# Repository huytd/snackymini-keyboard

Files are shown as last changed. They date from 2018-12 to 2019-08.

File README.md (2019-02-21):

# Snackymini Keyboard

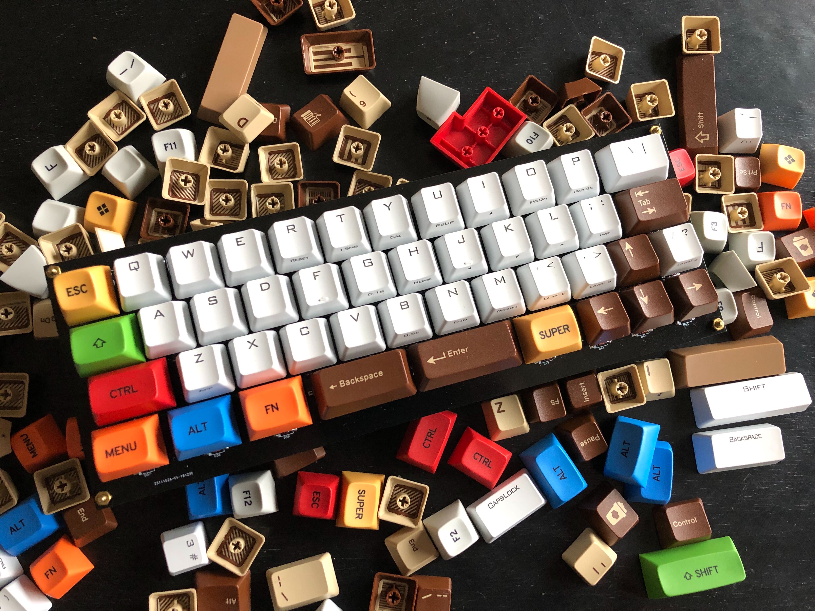
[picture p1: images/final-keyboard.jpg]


<details>
<summary>See more about design and PCB layout</summary>

**QWERTY Layout:**

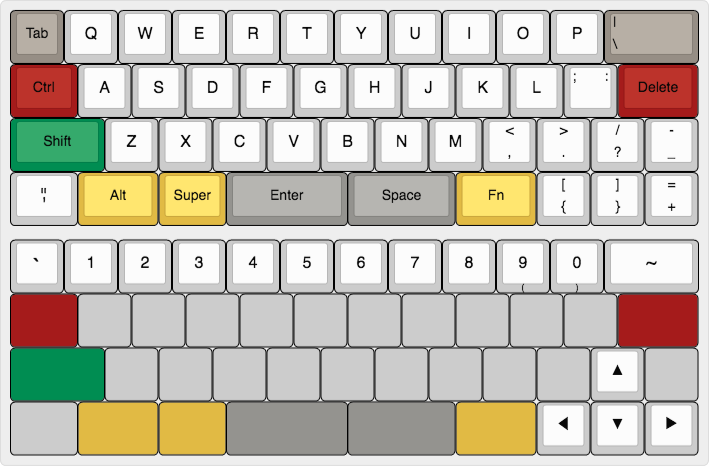
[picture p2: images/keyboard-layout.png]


**Dvorak Layout:**

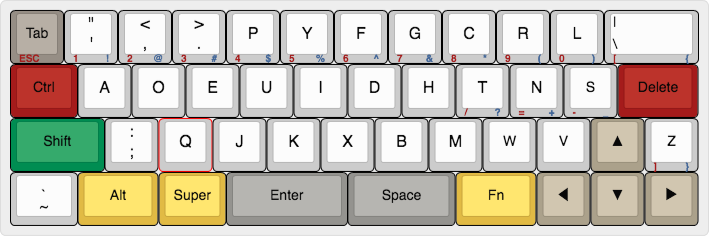
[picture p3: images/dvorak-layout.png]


Inspired by MiniVan Arrow Layout http://www.keyboard-layout-editor.com/#/gists/174470794149140f43dd6c9b544c168c

**Schema:**

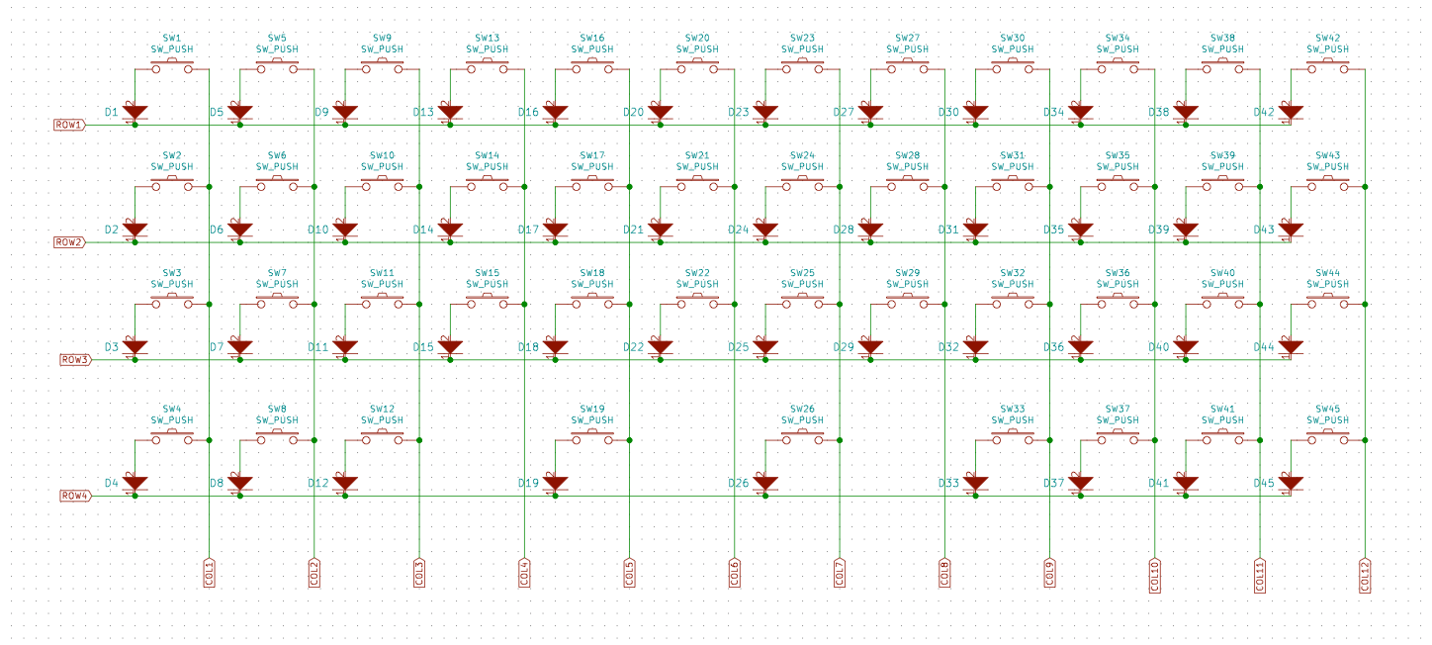
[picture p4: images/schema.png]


**PCB:**

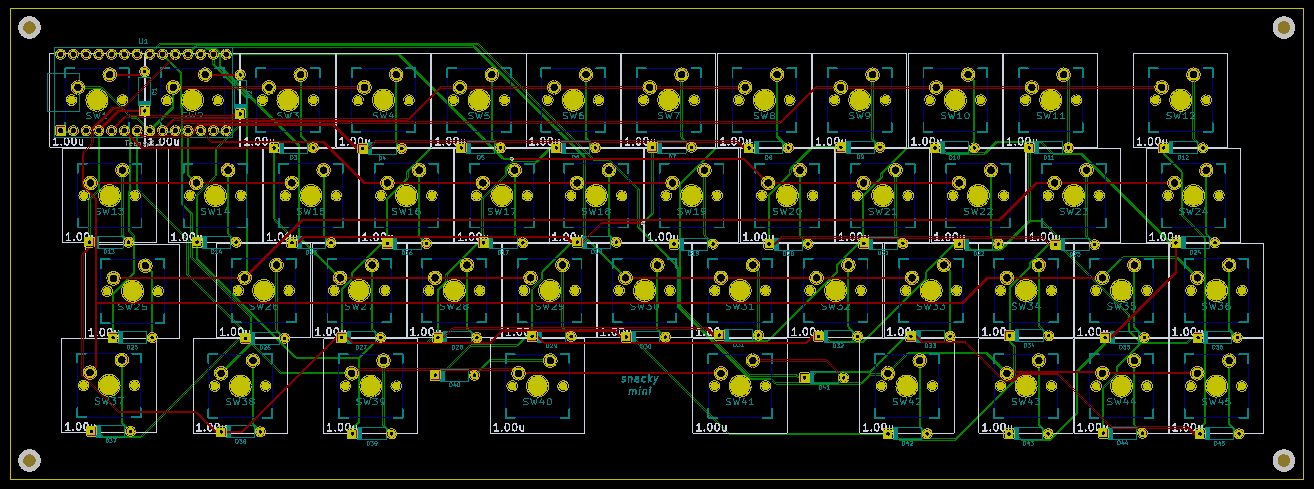
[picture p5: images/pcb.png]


**PCB render:**

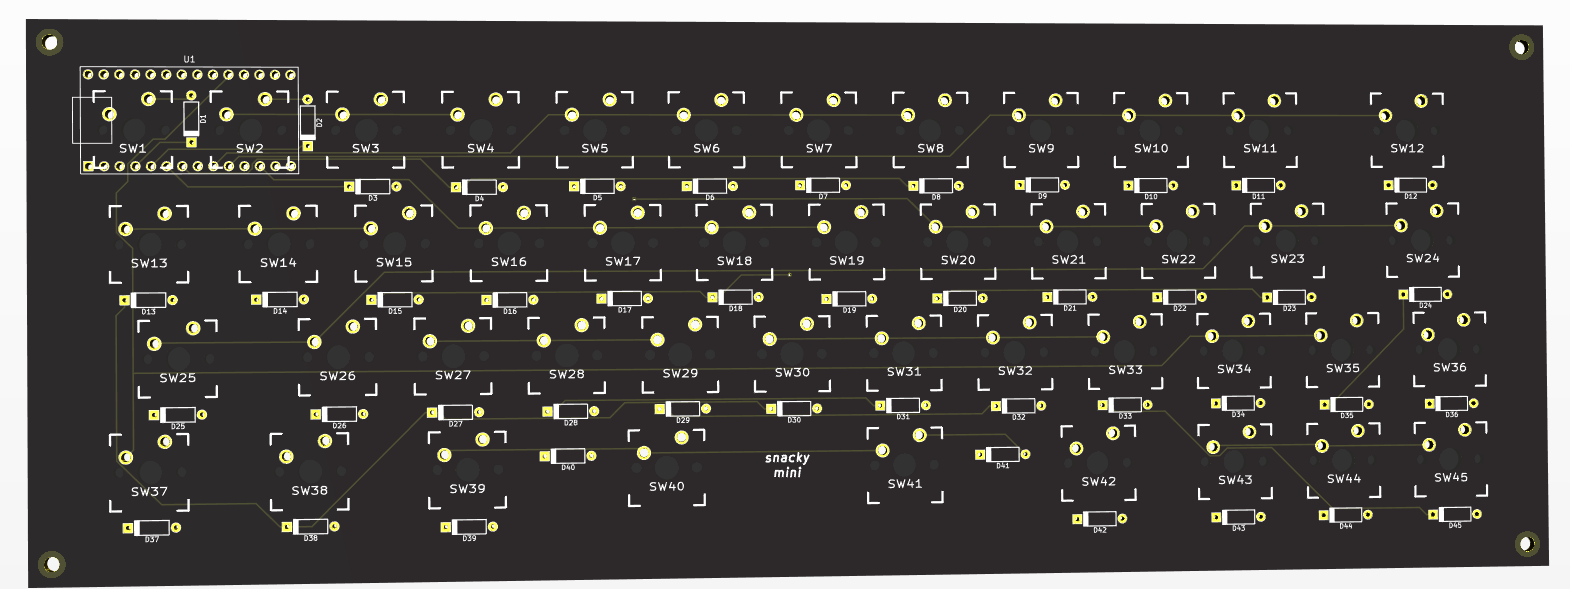
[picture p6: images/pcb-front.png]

</details>

## Parts
- 1x Teensy 3.2 with header pins
- 47x Cherry MX Switches (choose your color)
- 47x Key caps in various size
- 47x 1N4148 diodes

## How to use this repository?
First, you'll need to install [KiCad](http://kicad-pcb.org/), then you can open the PCB project in `hardware` folder to edit the PCB/Layout as you wish.

I have included the `snackymini-manufacturing-submission.zip` file containing all of the gerber files needed so you can send it to the manufacturer directly.

Ater having the PCB printed, you can use Arduino IDE (with Teensyduino installed) to compile the code in `firmware` folder, then upload it to your Teensy.

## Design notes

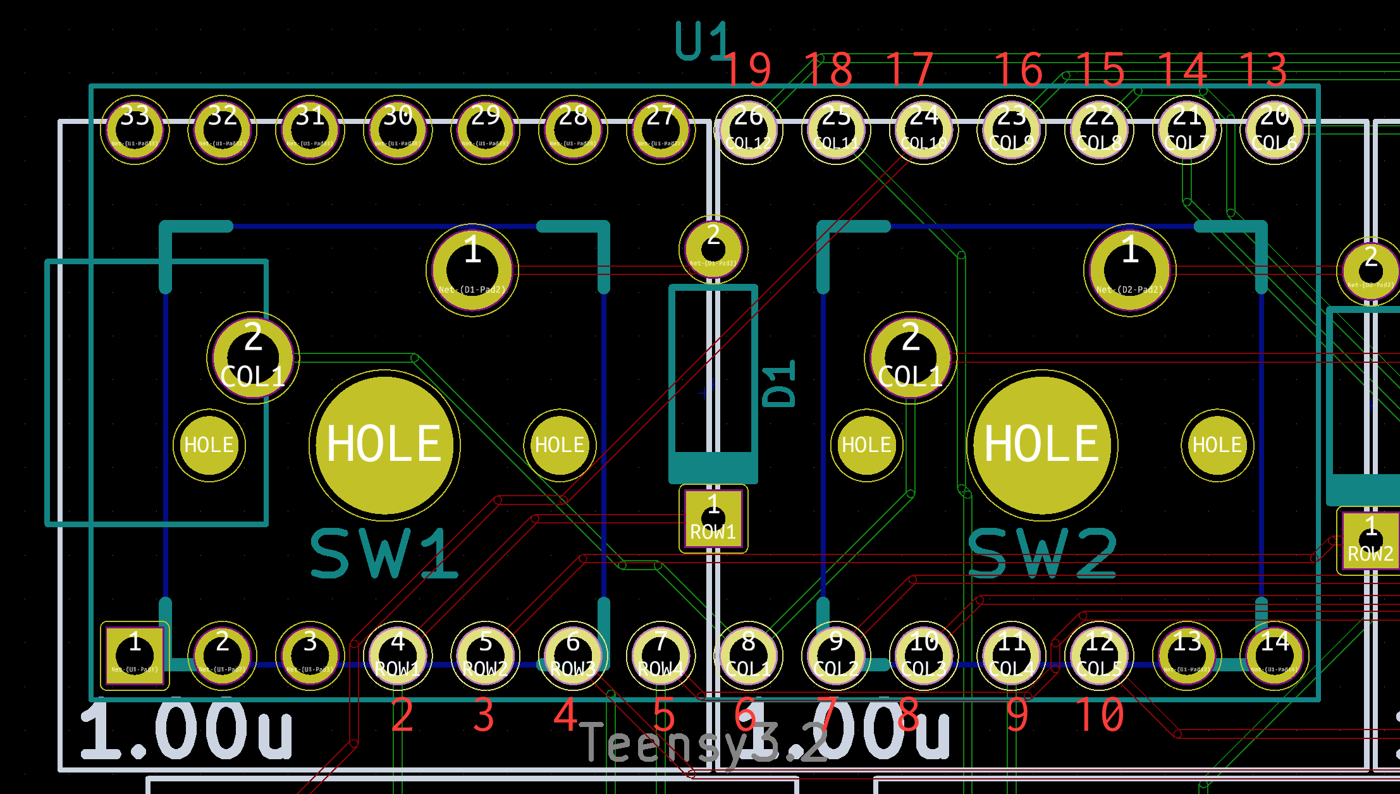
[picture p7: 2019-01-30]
images/pcb-pintout.png

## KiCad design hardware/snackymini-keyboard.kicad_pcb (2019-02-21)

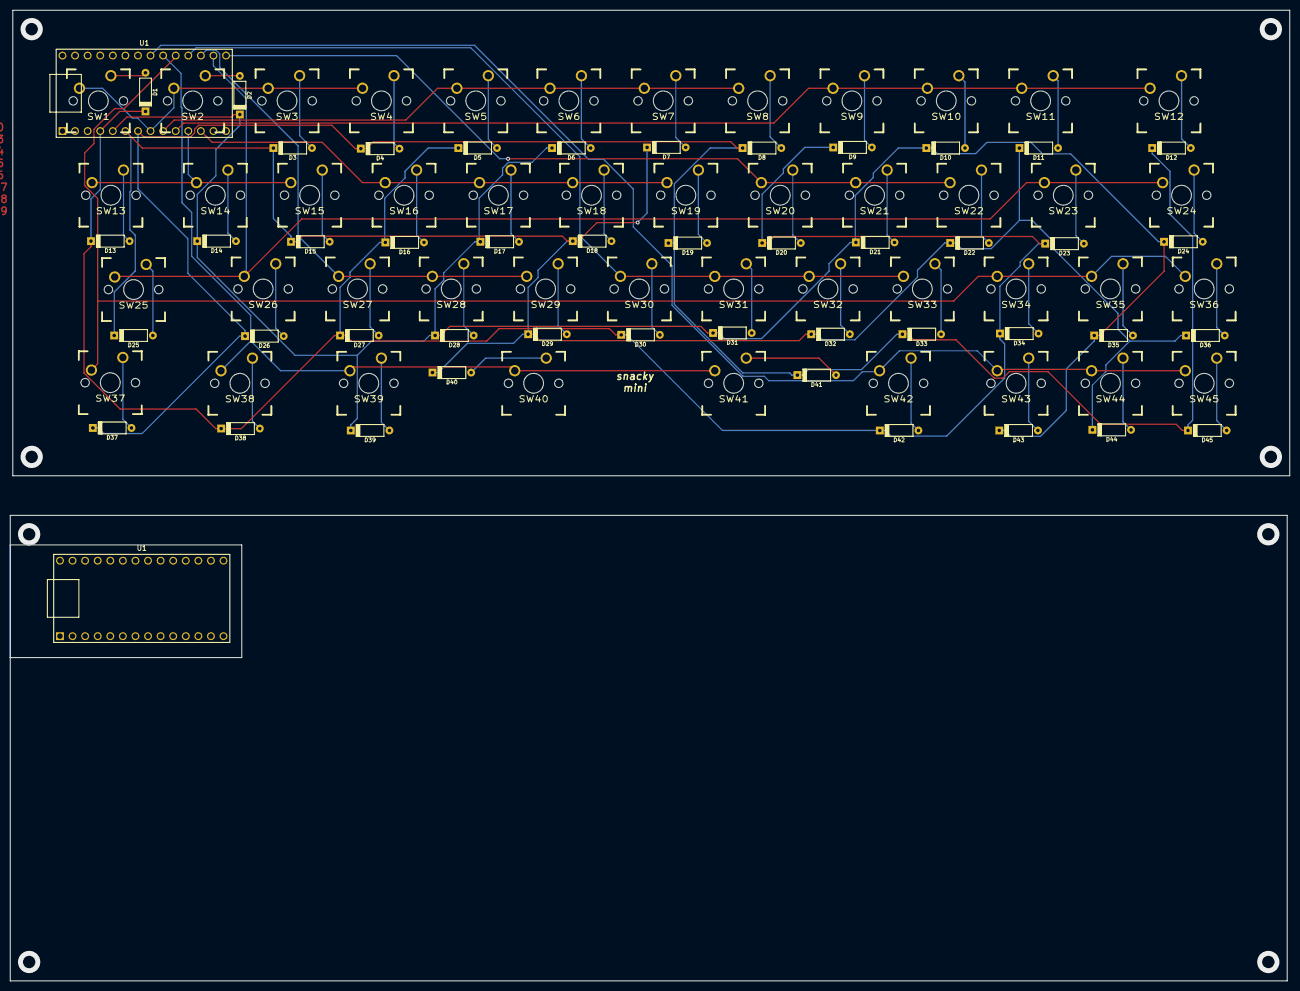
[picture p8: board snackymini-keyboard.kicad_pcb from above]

Board: 2 copper layers, 257.8 x 94.0 mm, 92 parts (0 on the bottom side), 61 nets.

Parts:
D1, D2, D3, D4, D5, D6, D7, D8, D9, D10, D11, D12, D13, D14, D15, D16, D17, D18, D19, D20, D21, D22, D23, D24, D25, D26, D27, D28, D29, D30, D31, D32, D33, D34, D35, D36, D37, D38, D39, D40, D41, D42, D43, D44, D45: D; D_axial
SW1, SW2, SW3, SW4, SW5, SW6, SW7, SW8, SW9, SW10, SW11, SW12, SW13, SW14, SW15, SW16, SW17, SW18, SW19, SW20, SW21, SW22, SW23, SW24, SW25, SW26, SW27, SW28, SW29, SW30, SW31, SW32, SW33, SW34, SW35, SW36, SW37, SW38, SW39, SW40, SW41, SW42, SW43, SW44, SW45: SW_PUSH; CHERRY_PLATE_100H
U1, U1#2: Teensy3.2; TeensySimple

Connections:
COL1: SW1.2, SW2.2, SW3.2, SW4.2, U1#2.8
COL2: SW5.2, SW6.2, SW7.2, SW8.2, U1#2.9
COL3: SW9.2, SW10.2, SW11.2, SW12.2, U1#2.10
COL4: SW13.2, SW14.2, SW15.2, U1#2.11
COL5: SW16.2, SW17.2, SW18.2, SW19.2, U1#2.12
COL6: SW20.2, SW21.2, SW22.2, U1#2.20
COL7: SW23.2, SW24.2, SW25.2, SW26.2, U1#2.21
COL8: SW27.2, SW28.2, SW29.2, U1#2.22
COL9: SW30.2, SW31.2, SW32.2, SW33.2, U1#2.23
COL10: SW34.2, SW35.2, SW36.2, SW37.2, U1#2.24
COL11: SW38.2, SW39.2, SW40.2, SW41.2, U1#2.25
COL12: SW42.2, SW43.2, SW44.2, SW45.2, U1#2.26
unnamed: D1.2, SW1.1
unnamed: D2.2, SW2.1
unnamed: D3.2, SW3.1
unnamed: D4.2, SW4.1
unnamed: D5.2, SW5.1
unnamed: D6.2, SW6.1
unnamed: D7.2, SW7.1
unnamed: D8.2, SW8.1
unnamed: D9.2, SW9.1
unnamed: D10.2, SW10.1
unnamed: D11.2, SW11.1
unnamed: D12.2, SW12.1
unnamed: D13.2, SW13.1
unnamed: D14.2, SW14.1
unnamed: D15.2, SW15.1
unnamed: D16.2, SW16.1
unnamed: D17.2, SW17.1
unnamed: D18.2, SW18.1
unnamed: D19.2, SW19.1
unnamed: D20.2, SW20.1
unnamed: D21.2, SW21.1
unnamed: D22.2, SW22.1
unnamed: D23.2, SW23.1
unnamed: D24.2, SW24.1
unnamed: D25.2, SW25.1
unnamed: D26.2, SW26.1
unnamed: D27.2, SW27.1
unnamed: D28.2, SW28.1
unnamed: D29.2, SW29.1
unnamed: D30.2, SW30.1
unnamed: D31.2, SW31.1
unnamed: D32.2, SW32.1
unnamed: D33.2, SW33.1
unnamed: D34.2, SW34.1
unnamed: D35.2, SW35.1
unnamed: D36.2, SW36.1
unnamed: D37.2, SW37.1
unnamed: D38.2, SW38.1
unnamed: D39.2, SW39.1
unnamed: D40.2, SW40.1
unnamed: D41.2, SW41.1
unnamed: D42.2, SW42.1
unnamed: D43.2, SW43.1
unnamed: D44.2, SW44.1
unnamed: D45.2, SW45.1
ROW1: D1.1, D5.1, D9.1, D13.1, D16.1, D20.1, D23.1, D27.1, D30.1, D34.1, D38.1, D42.1, U1#2.4
ROW2: D2.1, D6.1, D10.1, D14.1, D17.1, D21.1, D24.1, D28.1, D31.1, D35.1, D39.1, D43.1, U1#2.5
ROW3: D3.1, D7.1, D11.1, D15.1, D18.1, D22.1, D25.1, D29.1, D32.1, D36.1, D40.1, D44.1, U1#2.6
ROW4: D4.1, D8.1, D12.1, D19.1, D26.1, D33.1, D37.1, D41.1, D45.1, U1#2.7

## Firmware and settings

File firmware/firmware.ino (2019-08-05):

/* SnackyMini Keyboard Firmware
   By @huydotnet
   You must select Keyboard from the "Tools > USB Type" menu.
*/

#include <Keyboard.h>

// Comment this out to use QWERTY layout
//#define USE_DVORAK

#define ARROW_UP_KEY    91
#define ARROW_DOWN_KEY  112
#define ARROW_LEFT_KEY  111
#define ARROW_RIGHT_KEY 113
#define SHIFT_KEY       62
#define MENU_KEY        93
#define FN_KEY          110
#define BACKSPACE_KEY   61
#define ENTER_KEY       102
#define TAB_KEY         103
#define SUPER_KEY       101
#define CTRL_KEY        30
#define ALT_KEY         100
#define NULL_KEY        0x00

#ifndef KEY_BACKTICK
#define KEY_BACKTICK 53
#endif

#define ROWS           4
#define COLS           12
#define DEFAULT_LAYOUT 0
#define FN_LAYOUT      1

#define MAXIMUM_STROKES   10
#define DEBOUNCE_DELAY    15

const int SUPPORTED_STROKES = 6;
unsigned long lastFrame = 0;

// DO NOT EDIT
// The key code map of the board. I don't know why it's weird.
// Need to debug some day.
char refCode[ROWS][COLS] = {
  { 0 , 1  , 2  , 3  , 10 , 11 , 12 , 13 , 20 , 21 , 22 , 23  },
  { 30, 31 , 32 , 40 , 41 , 42 , 43 , 50 , 51 , 52 , 60 , 61  },
  { 62, 63 , 70 , 71 , 72 , 80 , 81 , 82 , 83 , 90 , 91 , 92  },
  { 93, 100, 101, 102, 255, 103, 255, 110, 255, 111, 112, 113 }
};

#ifndef USE_DVORAK
// QWERTY LAYOUT
uint8_t keyLayout[][ROWS][COLS] = {
  // Default layout
  {
   { KEY_TAB  , KEY_Q   , KEY_W   , KEY_E   , KEY_R   , KEY_T   , KEY_Y   , KEY_U   , KEY_I    , KEY_O     , KEY_P        , KEY_BACKSLASH },
   { NULL_KEY , KEY_A   , KEY_S   , KEY_D   , KEY_F   , KEY_G   , KEY_H   , KEY_J   , KEY_K    , KEY_L     , KEY_SEMICOLON, NULL_KEY      },
   { NULL_KEY , KEY_Z   , KEY_X   , KEY_C   , KEY_V   , KEY_B   , KEY_N   , KEY_M   , KEY_COMMA, KEY_PERIOD, KEY_SLASH     , KEY_MINUS     },
   { KEY_QUOTE, NULL_KEY, NULL_KEY, NULL_KEY, NULL_KEY, NULL_KEY, NULL_KEY, NULL_KEY, NULL_KEY , KEY_LEFT_BRACE  , KEY_RIGHT_BRACE     , KEY_EQUAL      }
  },
  // Fn layout
  {
   { KEY_TILDE , KEY_1   , KEY_2   , KEY_3   , KEY_4   , KEY_5   , KEY_6   , KEY_7   , KEY_8    , KEY_9         , KEY_0          , KEY_BACKTICK },
   { NULL_KEY, NULL_KEY, NULL_KEY, NULL_KEY, NULL_KEY, NULL_KEY, NULL_KEY, NULL_KEY, NULL_KEY , NULL_KEY, NULL_KEY, NULL_KEY  },
   { NULL_KEY, NULL_KEY, NULL_KEY, NULL_KEY, NULL_KEY, NULL_KEY, NULL_KEY, NULL_KEY, NULL_KEY, NULL_KEY     , KEY_UP       , NULL_KEY },
   { NULL_KEY, NULL_KEY, NULL_KEY, NULL_KEY, NULL_KEY, NULL_KEY, NULL_KEY, NULL_KEY, NULL_KEY , KEY_LEFT      , KEY_DOWN       , KEY_RIGHT  }
  }
};
#else
// DVORAK LAYOUT
uint8_t keyLayout[][ROWS][COLS] = {
  // Default layout
  {
   { KEY_TAB  , KEY_QUOTE    , KEY_COMMA, KEY_PERIOD, KEY_P   , KEY_Y   , KEY_F   , KEY_G   , KEY_C   , KEY_R   , KEY_L   , KEY_BACKSLASH },
   { NULL_KEY , KEY_A        , KEY_O    , KEY_E     , KEY_U   , KEY_I   , KEY_D   , KEY_H   , KEY_T   , KEY_N   , KEY_S   , NULL_KEY      },
   { NULL_KEY , KEY_SEMICOLON, KEY_Q    , KEY_J     , KEY_K   , KEY_X   , KEY_B   , KEY_M   , KEY_W   , KEY_V   , NULL_KEY, KEY_Z         },
   { KEY_TILDE, NULL_KEY     , NULL_KEY , NULL_KEY  , NULL_KEY, NULL_KEY, NULL_KEY, NULL_KEY, NULL_KEY, NULL_KEY, NULL_KEY, NULL_KEY      }
  },
  // Fn layout
  {
   { KEY_ESC , KEY_1   , KEY_2   , KEY_3   , KEY_4   , KEY_5   , KEY_6   , KEY_7   , KEY_8    , KEY_9    , KEY_0    , KEY_LEFT_BRACE },
   { NULL_KEY, NULL_KEY, NULL_KEY, NULL_KEY, NULL_KEY, NULL_KEY, NULL_KEY, NULL_KEY, KEY_SLASH, KEY_EQUAL, KEY_MINUS, NULL_KEY       },
   { NULL_KEY, NULL_KEY, NULL_KEY, NULL_KEY, NULL_KEY, NULL_KEY, NULL_KEY, NULL_KEY, NULL_KEY , NULL_KEY , NULL_KEY , KEY_RIGHT_BRACE},
   { NULL_KEY, NULL_KEY, NULL_KEY, NULL_KEY, NULL_KEY, NULL_KEY, NULL_KEY, NULL_KEY, NULL_KEY , NULL_KEY , NULL_KEY , NULL_KEY       }
  }
};
#endif

int rowPins[ROWS] = { 23, 22, 21, 20 };
int colPins[COLS] = { 19, 18, 17, 16, 15, 12, 11, 10, 9, 8, 7, 6 };

struct Key {
  int row;
  int col;
  int code;
};

struct Point {
  int r;
  int c;
};

struct Point keyToPoint(int code) {
  struct Point p;
  p.r = -1; p.c = -1;
  for (int r = 0; r < ROWS; r++) {
    for (int c = 0; c < COLS; c++) {
      if (refCode[r][c] == code) {
        p.r = r; p.c = c;
      }
    }
  }
  return p;
}

// Key Scanning Algorithm
struct Key* readKey() {
  struct Key* result = (Key*)malloc(MAXIMUM_STROKES * sizeof(struct Key));
  for (int i = 0; i < MAXIMUM_STROKES; i++) {
    result[i].col = -1;
    result[i].row = -1;
    result[i].code = -1;
  }
  int cur = 0;

  for (int row = 0; row < ROWS; row++) {
    pinMode(rowPins[row], OUTPUT);
    digitalWrite(rowPins[row], LOW);
    for (int col = 0; col < COLS; col++) {
      if (digitalRead(colPins[col]) == LOW) {
        result[cur].row = row;
        result[cur].col = col;
        result[cur].code = col * 10 + row;
        if (cur < MAXIMUM_STROKES) cur++;
      }
    }
    pinMode(rowPins[row], INPUT);
    digitalWrite(rowPins[row], LOW);
  }

  return result;
}

void setKey(int id, uint8_t code) {
  switch (id) {
  case 0: Keyboard.set_key1(code); break;
  case 1: Keyboard.set_key2(code); break;
  case 2: Keyboard.set_key3(code); break;
  case 3: Keyboard.set_key4(code); break;
  case 4: Keyboard.set_key5(code); break;
  case 5: Keyboard.set_key6(code); break;
  }
}

void submitLayout(struct Key* keys, uint8_t layout[ROWS][COLS]) {
  int modifiers = 0;
  int rolloverCount = 0;
  Keyboard.set_modifier(0);
  for (int i = 0; i < SUPPORTED_STROKES; i++) {
    setKey(i, 0);
  }
  for (int i = 0; i < SUPPORTED_STROKES; i++) {
    #ifdef USE_DVORAK
    if (keys[i].code == ARROW_UP_KEY) {
      Keyboard.set_key1(KEY_UP);
    }
    else if (keys[i].code == ARROW_DOWN_KEY) {
      Keyboard.set_key1(KEY_DOWN);
    }
    else if (keys[i].code == ARROW_LEFT_KEY) {
      Keyboard.set_key1(KEY_LEFT);
    }
    else if (keys[i].code == ARROW_RIGHT_KEY) {
      Keyboard.set_key1(KEY_RIGHT);
    }
    #endif
    if (keys[i].code == SUPER_KEY) {
      modifiers |= MODIFIERKEY_GUI;
    }
    else if (keys[i].code == CTRL_KEY) {
      modifiers |= MODIFIERKEY_CTRL;
    }
    else if (keys[i].code == ALT_KEY) {
      modifiers |= MODIFIERKEY_ALT;
    }
    else if (keys[i].code == SHIFT_KEY) {
      modifiers |= MODIFIERKEY_SHIFT;
    }
    else if (keys[i].code == BACKSPACE_KEY) {
      Keyboard.set_key1(KEY_BACKSPACE);
    }
    else if (keys[i].code == TAB_KEY) {
      Keyboard.set_key1(KEY_SPACE);
    }
    else if (keys[i].code == ENTER_KEY) {
      Keyboard.set_key1(KEY_ENTER);
    }
    else {
      if (keys[i].code != -1) {
        struct Point pos = keyToPoint(keys[i].code);
        int c = layout[pos.r][pos.c];
        if (c != NULL_KEY) {
          setKey(rolloverCount, c);
          rolloverCount++;
        }
      }
    }
  }
  if (modifiers) {
    Keyboard.set_modifier(modifiers);
  }
  Keyboard.send_now();
}

void keySubmit(struct Key* keys) {
  int layoutId = DEFAULT_LAYOUT;
  for (int i = 0; i < SUPPORTED_STROKES; i++) {
    if (keys[i].code == FN_KEY) {
      layoutId = FN_LAYOUT; break;
    }
  }
  submitLayout(keys, keyLayout[layoutId]);
}

/* Life Cycle Functions */

void setup()
{
  Serial.begin(9600);
  for (int i = 0; i < ROWS; i++) {
    pinMode(rowPins[i], INPUT);
    digitalWrite(rowPins[i], HIGH);
  }
  
  for (int i = 0; i < COLS; i++) {
    pinMode(colPins[i], INPUT);
    digitalWrite(colPins[i], HIGH);
  }
}

void loop()
{
  unsigned long timeNow = millis();
  if (timeNow - lastFrame > DEBOUNCE_DELAY) {
    lastFrame = timeNow;
    struct Key* keys = readKey();
    if (keys[0].row != -1 && keys[0].col != -1) {
      keySubmit(keys);
    } else {
      Keyboard.set_modifier(0);
      for (int i = 0; i < SUPPORTED_STROKES; i++) {
        setKey(i, 0);
      }
      Keyboard.send_now();
    }
    free(keys);
  }
}

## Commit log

2018-12-23 Update layout and routing, add corner mount hole
    [snackymini-keyboard-B.Cu.gbr, snackymini-keyboard-B.Mask.gbr, snackymini-keyboard-B.Paste.gbr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]
2019-01-30 Update PCB pinout
    [snackymini-keyboard.kicad_pcb]
2019-02-06 Re-organizing the project
    [snackymini-keyboard-B.Cu.gbr, snackymini-keyboard-B.Mask.gbr, snackymini-keyboard-B.Paste.gbr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]
2019-02-07 Fix issue keyboard could not send number 3 keys.
    The reason behind this is, I was using space character
    as a flag for empty key, it is also conflict with the
    number 3 keys which has the value of 0x20, also a space.
    LOL.
    [firmware.ino]
2019-02-07 Refactoring and reformatting, also added a device name config
2019-02-21 Add some measurement
    [snackymini-keyboard.kicad_pcb]
